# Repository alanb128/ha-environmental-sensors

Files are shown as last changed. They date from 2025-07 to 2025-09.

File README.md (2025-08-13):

# Environmental sensors
Two different sensor projects that can be used standalone or with Home Assistant

Watch the video: https://youtu.be/DV3xqJKjhDA

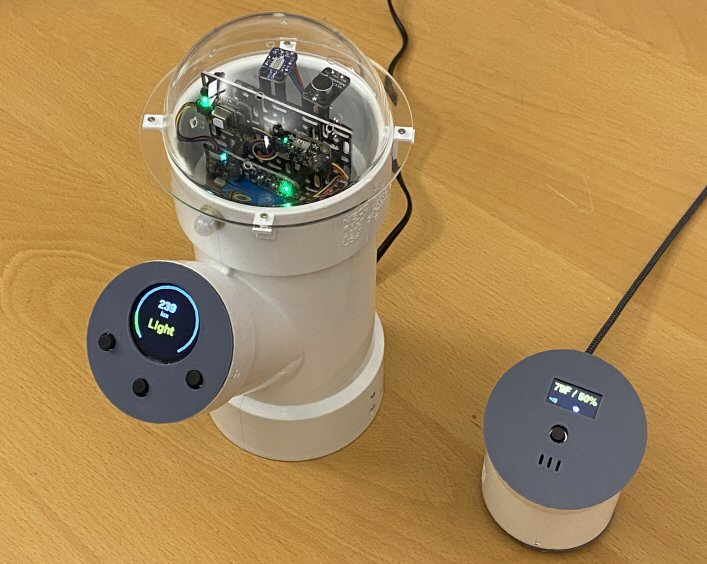
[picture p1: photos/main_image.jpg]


Disclaimer: These devices are not for any safety, medical, or critical usage. It's for hobby education and experimentation only!

## Mini-sensor

This one is designed to be inexpensive and easy to build. The parts should cost around $25. It measures temperature and humidity, and can publish the sensor readings to Home Assistant.

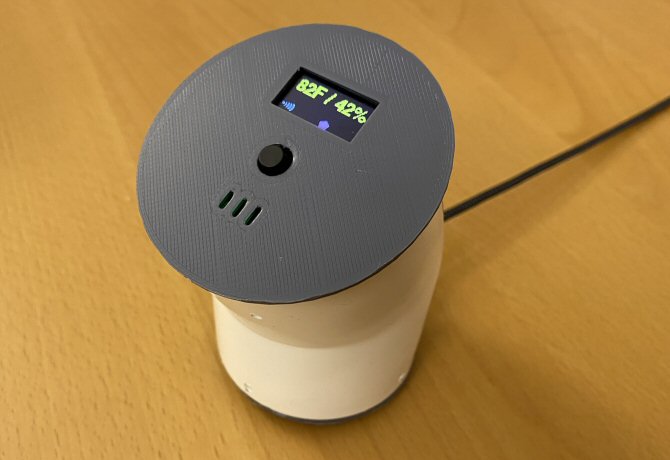
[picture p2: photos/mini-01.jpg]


### Hardware List

- [Raspberry Pi Pico 2W](https://www.raspberrypi.com/products/raspberry-pi-pico-2/) microcontroller
- The case is based on a "2 Inch 22.5 Degree PVC Elbow Pipe Fitting" [like this one](https://www.amazon.com/dp/B0DZS46D2V)
- Display (optional) [Adafruit 0.96" 160x80 Color TFT Display](https://www.adafruit.com/product/3533) - ST7735
- 12mm x 12mm momentary tactile button (optional)
- Some wire or ribbon cable, 28AWG or similar
- [3cm x 7cm proto board](https://www.adafruit.com/product/4784) (only one board needed per sensor)
- [SHT40 Temperature and Humidity Sensor](https://www.adafruit.com/product/4885) (or SHT41, SHT45)
- M2 x 12 self tapping screws (optional) - 4 pieces to secure top and bottom to case

If not using the display, you can use an LED instead:
- bi-color LED
- two 470 ohm resistors

### Assembly

3D print the top, bottom, and insulator. Then use the photos below to help assemble the unit. The file `schematic-mini.pdf` shows how to wire everything together.

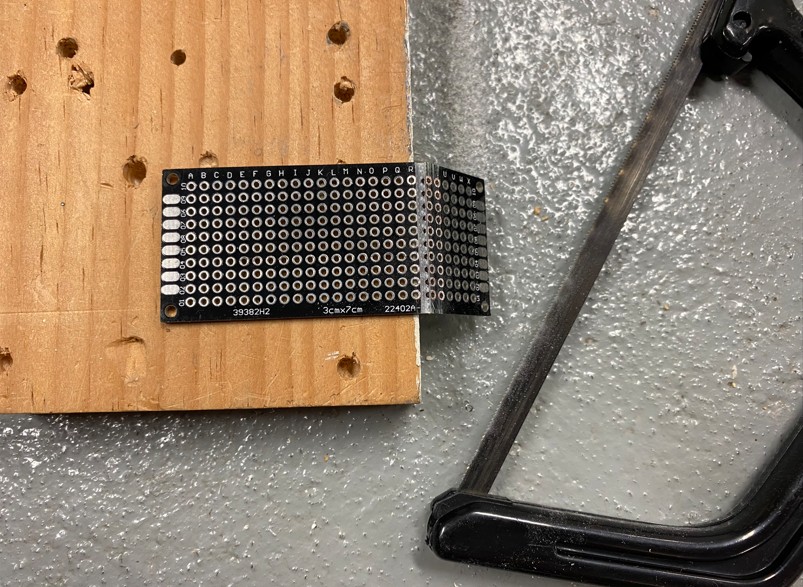
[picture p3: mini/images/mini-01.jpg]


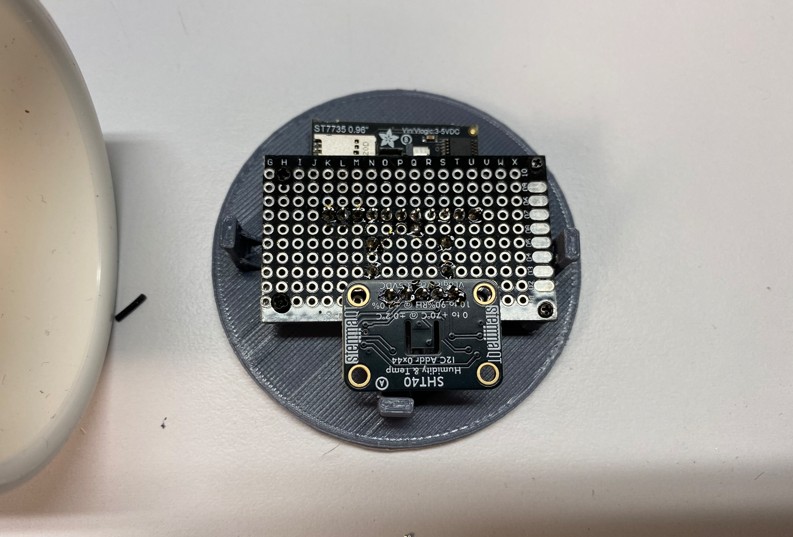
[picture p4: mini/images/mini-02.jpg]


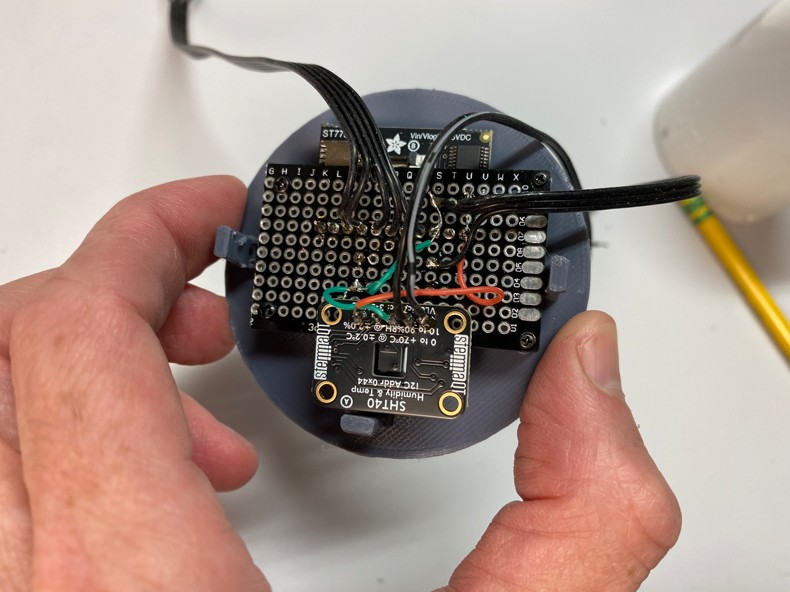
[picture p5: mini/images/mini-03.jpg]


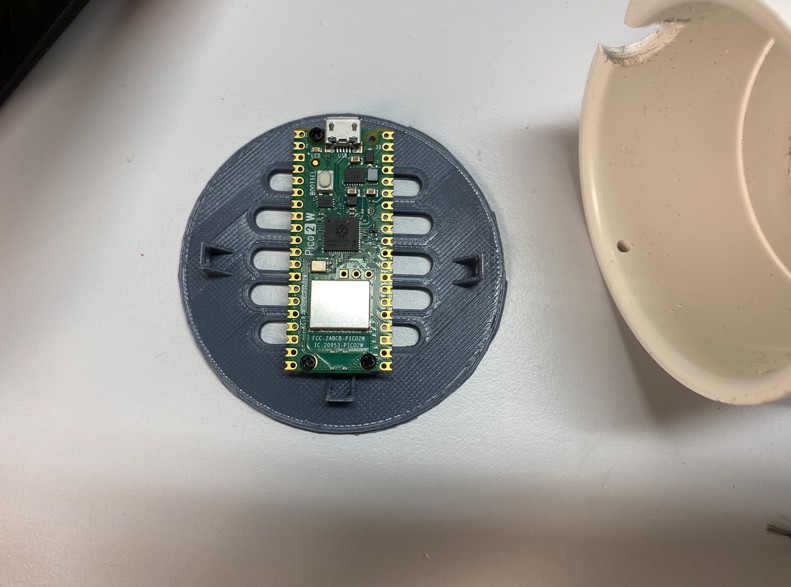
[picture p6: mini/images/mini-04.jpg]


### Software

[Download and install](https://circuitpython.org/board/raspberry_pi_pico2_w/) Circuitpython for the Pico 2W. This code was developed and tested on version 9.2.7, but should work on newer versions. 

Copy all of the files in the mini folder to the root of your Pico. (This includes all of the code and icons needed to run the project) You'll be replacing the default code.py file if it already exists.  

You will need to find and download the font file `Helvetica-Bold-16.bdf` to the root of the Pico as well. (I can't host it here due to its proprietary nature.)

Edit the `settings.toml` file with your WiFi SSID and password.

Add the following libraries to the Lib folder on the device: (You can find them in [the bundles](https://circuitpython.org/libraries) for version 9.x)

- adafruit_bitmap_font
- adafruit_minimqtt
- adafruit_display_text
- adafuit_ticks
- adafruit_st7735r
- adafruit_sht4x
- adafruit_connection_manager

### Operation

Provide 5v 1A or greater to the Pico's micro usb port to power the device and start the code automatically. Update the settings file to publish via MQTT.

## Maxi

This one has up to ten sensors and is a more advanced project. The full code and some build suggestions are in this repo, but you'll need to improvise a little bit for best results.

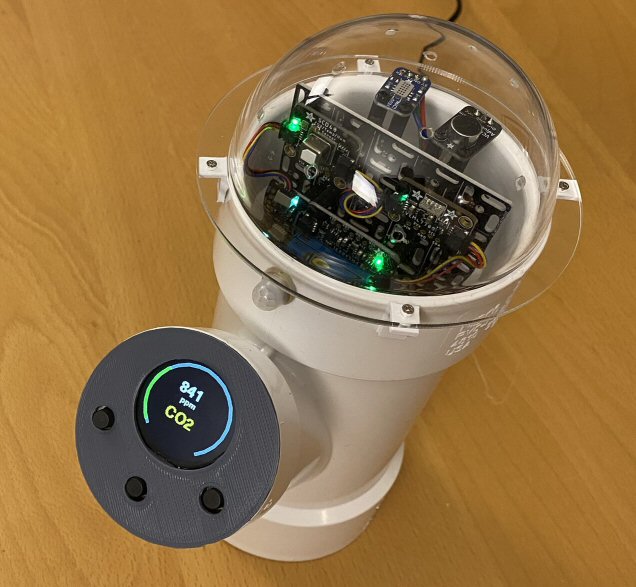
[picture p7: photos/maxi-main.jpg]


### Hardware List

- [Raspberry Pi Pico 2W](https://www.raspberrypi.com/products/raspberry-pi-pico-2/) microcontroller
- The case is based on a "Reducing" pipe fitting, [like this one](https://www.homedepot.com/p/Charlotte-Pipe-3-in-x-3-in-x-2-in-DWV-PVC-Wye-Reducing-PVC006011400HD/203396277) 
- 12mm x 12mm momentary tactile buttons (three)
- Some wire or ribbon cable, 28AWG or similar
- [Swirly Aluminum Grids](https://www.adafruit.com/product/5774) (mix and match, cut to size if needed)
- [Basic PIR Sensor like the BL412](https://www.adafruit.com/product/4667) 
- [Adafruit EYESPI breakout board](https://www.adafruit.com/product/5613) For connecting display ribbon cable to the Pico
- [MAX 4466 electret microphone](https://www.adafruit.com/product/1063)
- [Tiny Code Reader from Useful Sensors](https://www.adafruit.com/product/5744)
- [Adafruit MiCS5524 gas sensor](https://www.adafruit.com/product/3199)
- [DPS 310 Pressure sensor](https://www.adafruit.com/product/4494)
- [Accelerometer](https://www.adafruit.com/product/2809)
- [VEML7700 Lux Sensor](https://www.adafruit.com/product/4162)
- [SCD 40](https://www.adafruit.com/product/5187) CO2 sensor
- [Adafruit PMSA003I Air Quality Breakout](https://www.adafruit.com/product/4632)
- [4 channel I2C-safe logic level converter](https://www.adafruit.com/product/757)
- [Adafruit 1.28" 240x240 Round TFT LCD](https://www.adafruit.com/product/6178)
- Qwiic/STEMMAQT connectors/cables to connect the sensors together
- M2.5 spacers, standoffs and hardware for mounting sensors
- [3cm x 7cm proto board](https://www.adafruit.com/product/4784) - cut as needed
- 5V, 4A power supply
- The top dome (optional) is a CCTV clear dome [like this one](https://www.amazon.com/dp/B07L6GLTNP)

Optional:
- blue LED and resistor
- acrylic security camera dome

### Assembly

3D print the control panel, bottom bracket, and clips. Then use the photos below to help assemble the unit. The file `schematic-maxi.pdf` shows how to wire everything together.

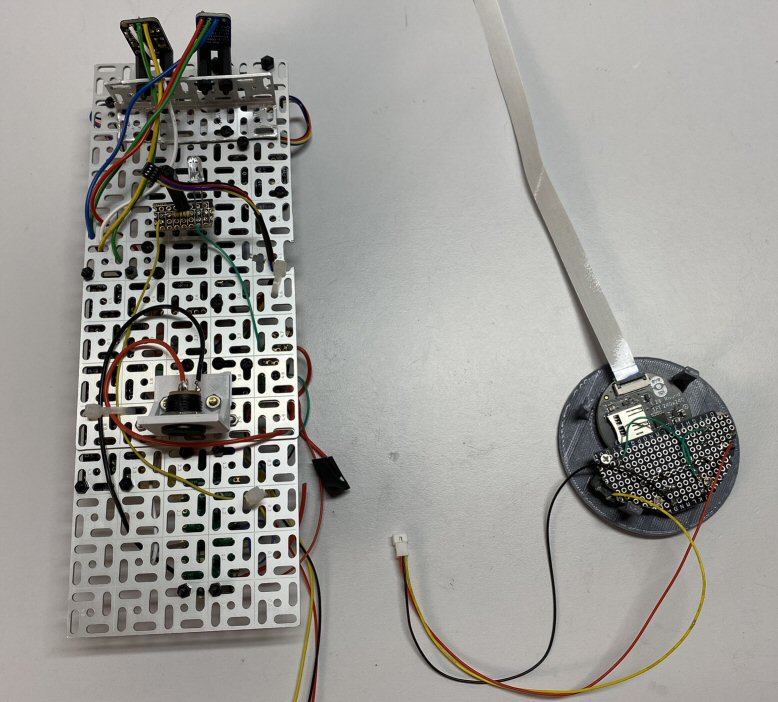
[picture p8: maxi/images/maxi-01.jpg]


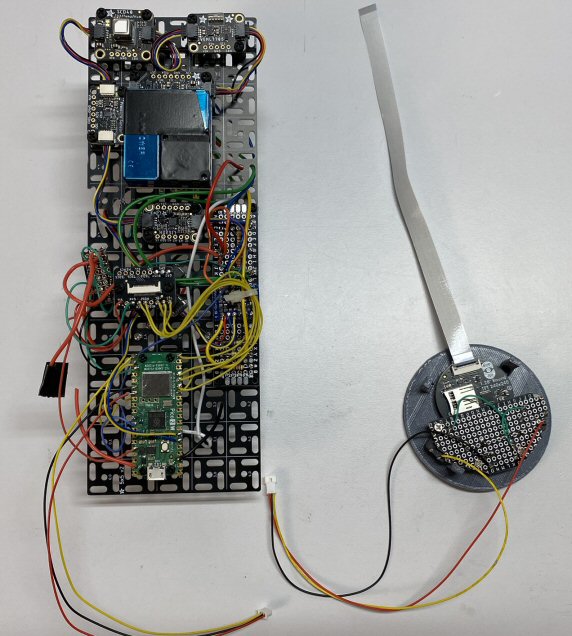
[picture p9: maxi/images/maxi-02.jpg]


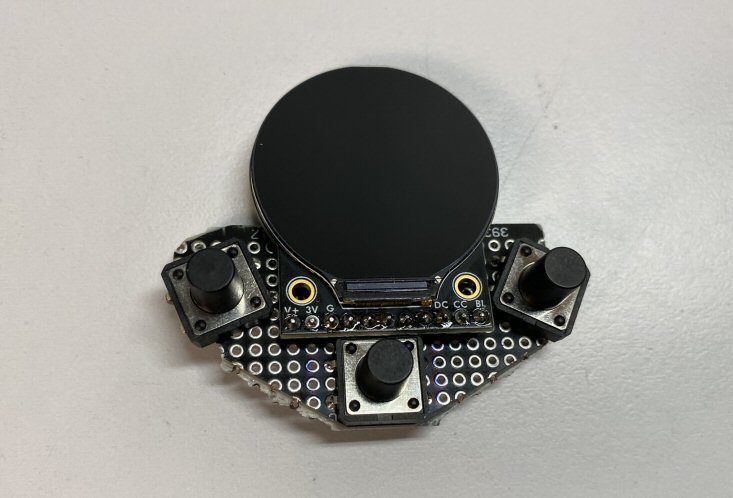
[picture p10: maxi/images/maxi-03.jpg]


### Software

[Download and install](https://circuitpython.org/board/raspberry_pi_pico2_w/) Circuitpython for the Pico 2W. This code was developed and tested on version 9.2.7, but should work on newer versions. 

Copy all of the files in the maxi folder to the root of your Pico. (This includes all of the code and icons needed to run the project) You'll be replacing the default code.py file if it already exists.  

You will need to find and download the font file `Helvetica-Bold-16.bdf` to the root of the Pico as well. (I can't host it here due to its proprietary nature.)

Edit the `settings.toml` file with your WiFi SSID and password.

Add the following libraries to the Lib folder on the device: (You can find them in [the bundles](https://circuitpython.org/libraries) for version 9.x)

- adafruit_bitmap_font
- adafruit_bus_device
- adafruit_display_shapes
- adafruit_minimqtt
- adafruit_display_text
- adafruit_imageload
- adafruit_dps310
- adafruit_pm25
- adafruit_register
- adafuit_ticks
- adafruit_gc9a01a
- adafruit_lis3dh
- adafruit_scd4x
- adafruit_veml7700
- adafruit_connection_manager

### Operation

Provide 5v 4A or greater to the Pico's VSYS pin to power the device and start the code automatically. Update the settings file to publish via MQTT. Note that most of the I2C sensors need to be powered by the 5V supply and then connected to the Pico through the logic level shifter. (See the schematic) When trying to power everything on the I2C bus with 3V, the sensors would brown out every few seconds. Make sure the sensors you choose are all 5V tolerant. (The ones in the parts list are.)

## Connecting to Home Assistant

You will need an MQTT broker running on your network. [Mosquitto](https://mosquitto.org/) is a good choice!

Then, [add the sensors](https://www.home-assistant.io/integrations/sensor.mqtt/) and binary sensors to your configuration.yaml file in Home Assistant. 

For an example of the House Map dashboard configuration, see the `house-map.txt` file in this repo. Note that it uses an image uploaded to the Home Assistant media folder.

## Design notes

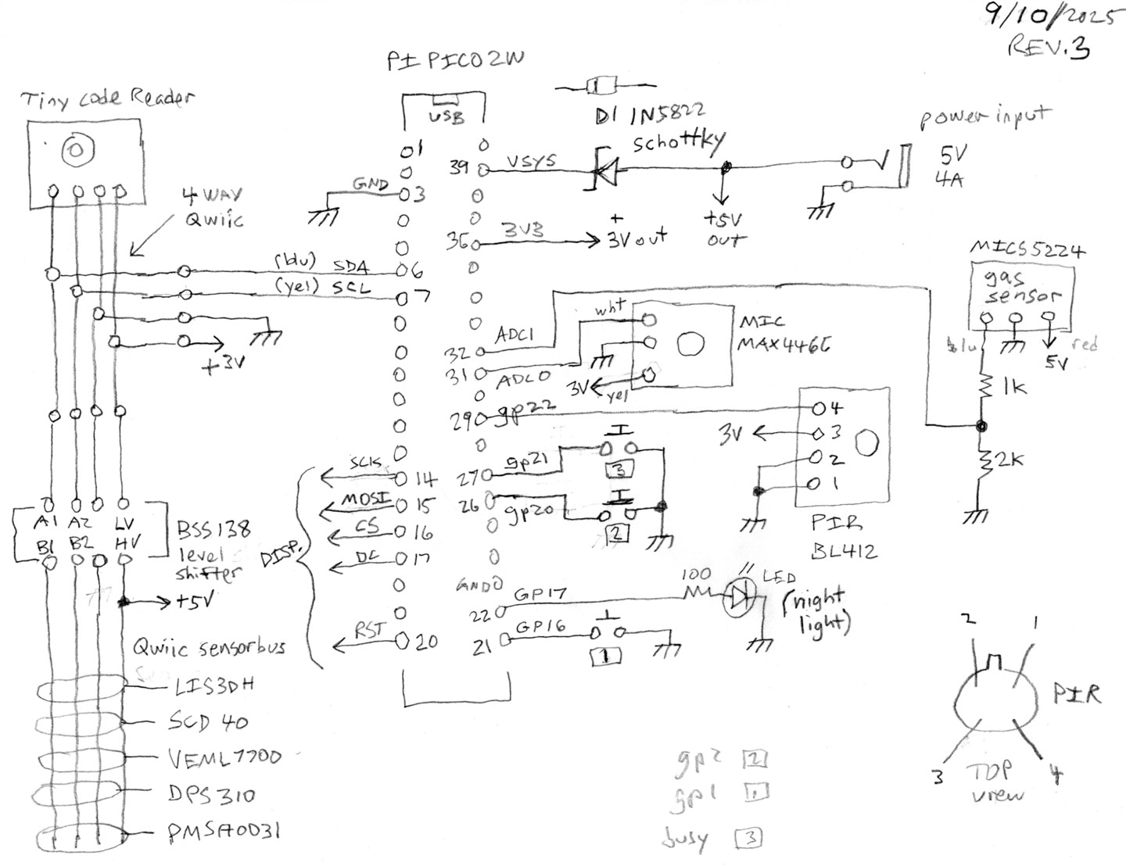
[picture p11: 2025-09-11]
schematic-maxi.jpg

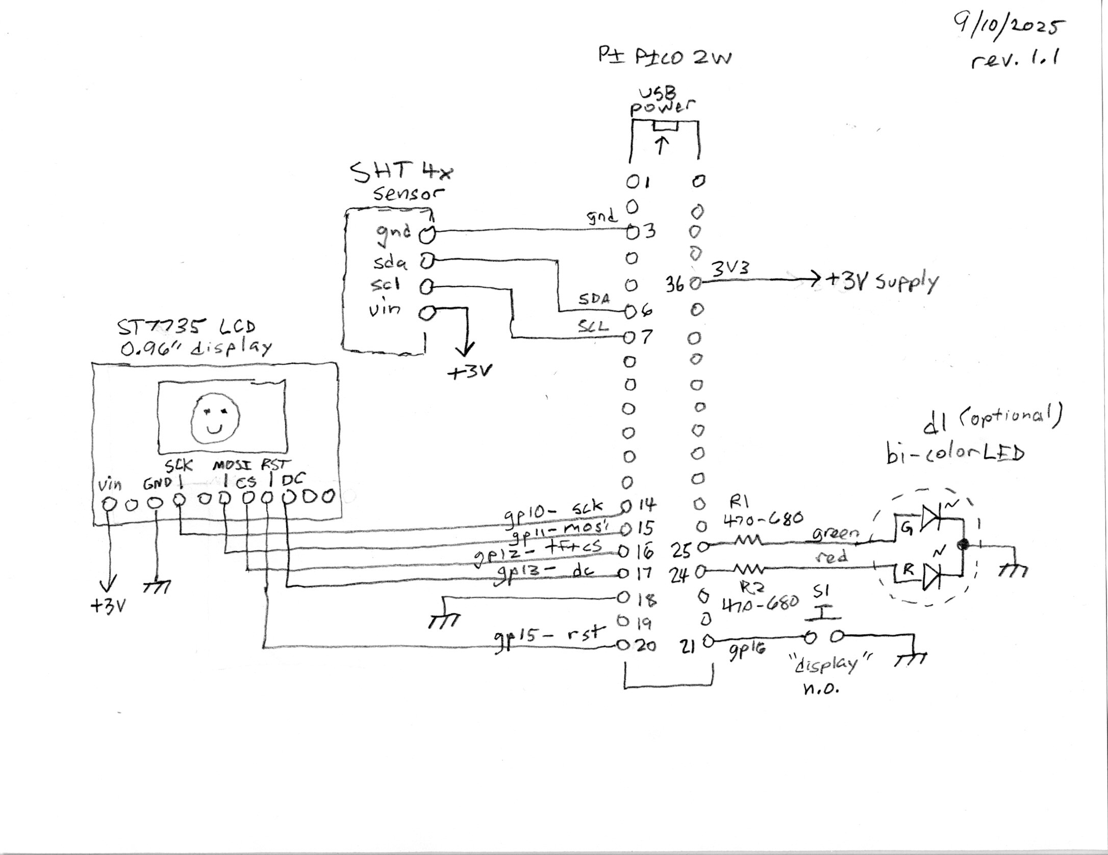
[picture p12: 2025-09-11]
schematic-mini.jpg

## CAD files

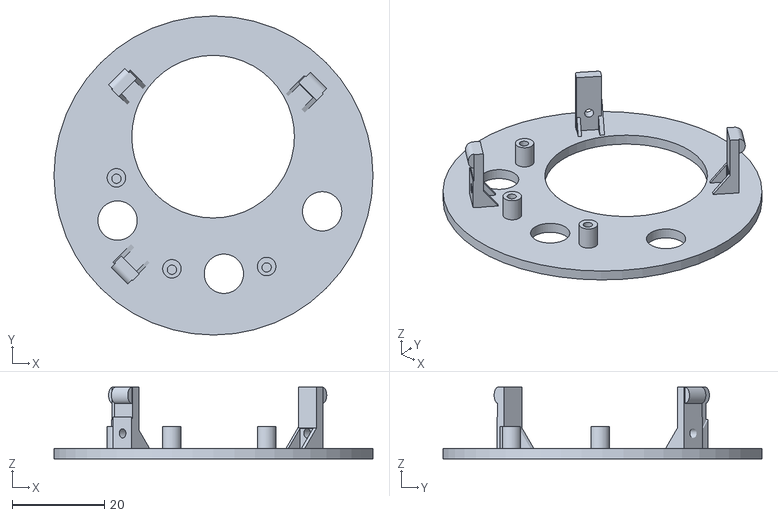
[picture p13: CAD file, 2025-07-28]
maxi/stl/control-panel.stl
69.0 x 69.0 x 15.5

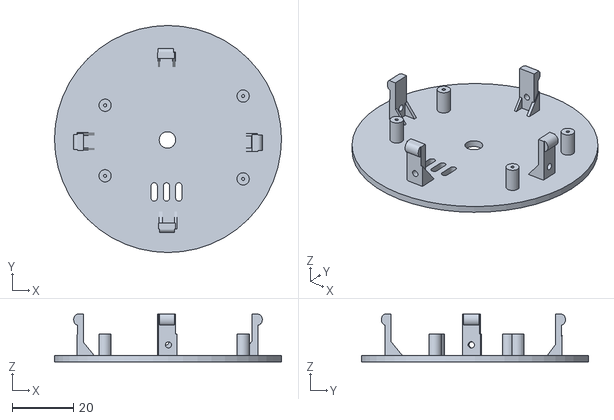
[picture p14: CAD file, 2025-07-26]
mini/stl/top-no-lcd.stl
74.0 x 74.0 x 15.5

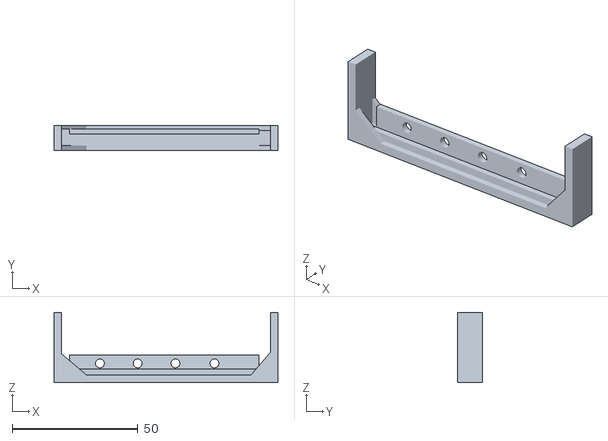
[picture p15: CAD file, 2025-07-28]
maxi/stl/bottom-bracket.stl
89.0 x 10.0 x 28.0

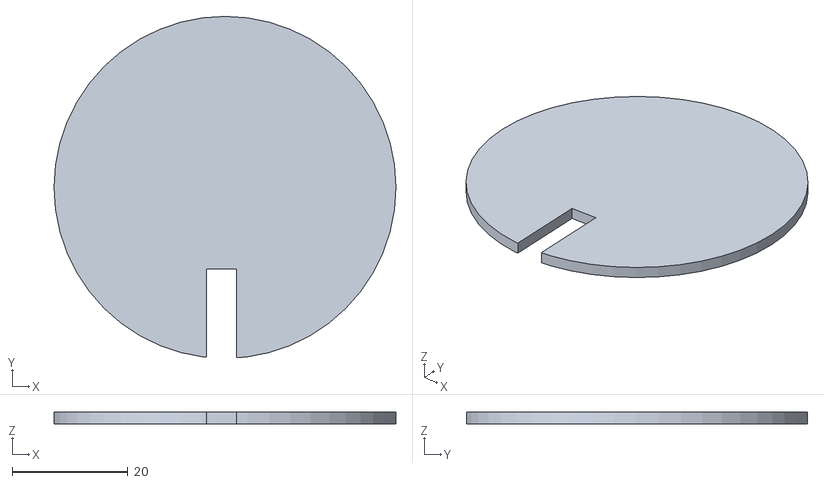
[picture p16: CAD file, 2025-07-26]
mini/stl/insulator.stl
59.0 x 58.9 x 2.00

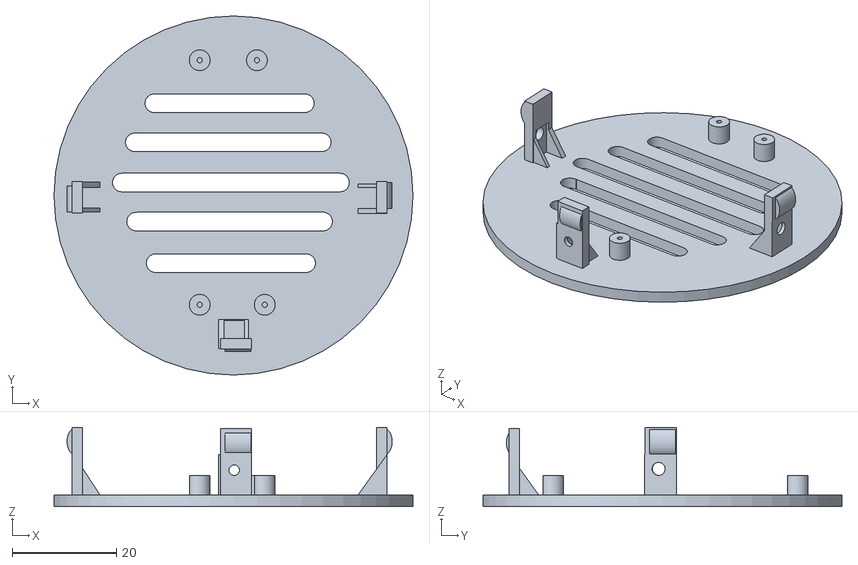
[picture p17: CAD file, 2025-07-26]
mini/stl/bottom.stl
69.0 x 69.0 x 15.2

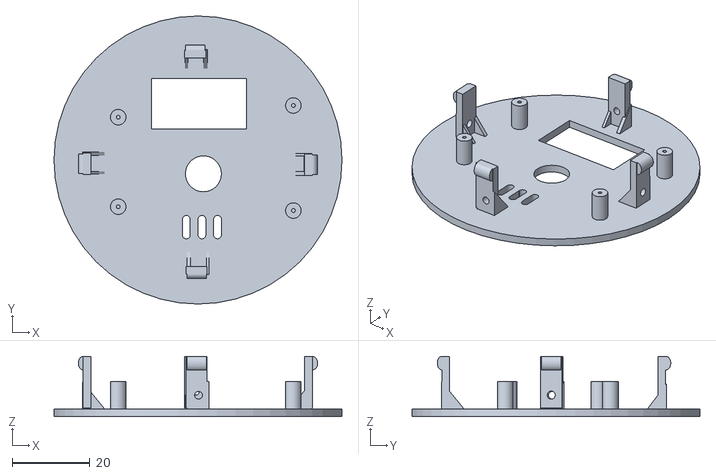
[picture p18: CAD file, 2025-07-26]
mini/stl/top.stl
74.0 x 74.0 x 15.5

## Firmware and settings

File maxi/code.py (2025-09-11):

# SPDX-FileCopyrightText: 2021 ladyada for Adafruit Industries
# SPDX-License-Identifier: MIT

import time
import os
import board
import busio
import digitalio
from analogio import AnalogIn
import microcontroller
import struct

import adafruit_lis3dh
from digitalio import DigitalInOut, Direction, Pull

from adafruit_pm25.i2c import PM25_I2C
from adafruit_dps310.basic import DPS310
import adafruit_veml7700
import adafruit_scd4x

import displayio
import terminalio
from adafruit_display_text.bitmap_label import Label
import adafruit_imageload
from fourwire import FourWire
from vectorio import Circle
from adafruit_gc9a01a import GC9A01A
from adafruit_display_shapes.arc import Arc
from adafruit_bitmap_font import bitmap_font
from adafruit_display_text import label

import ipaddress
import wifi
import socketpool
import ssl
import adafruit_minimqtt.adafruit_minimqtt as MQTT

print("Hello.")

def take_reading(sensor):
    
    global pm10
    global pm25
    global hum
    pm1 = 0
    co2 = 0
    reading = 0
      
    if sensor == "PM1":
    
        try:
            aqdata = pm_25.read()
            # print(aqdata)
            print()
            print("Concentration Units (standard)")
            print("---------------------------------------")
            print(
                "PM 1.0: %d\tPM2.5: %d\tPM10: %d"
                % (aqdata["pm10 standard"], aqdata["pm25 standard"], aqdata["pm100 standard"])
            )
            pm25 = aqdata["pm25 standard"]
            pm10 = aqdata["pm100 standard"]
            pm1 = aqdata["pm10 standard"]
        except Exception as e:
            print("Unable to read from PM sensor: {}; retrying...".format(e))
            time.sleep(1.2)
            try:
                aqdata = pm_25.read()
                # print(aqdata)
                print()
                print("Concentration Units (standard)")
                print("---------------------------------------")
                print(
                    "PM 1.0: %d\tPM2.5: %d\tPM10: %d"
                    % (aqdata["pm10 standard"], aqdata["pm25 standard"], aqdata["pm100 standard"])
                )
                pm25 = aqdata["pm25 standard"]
                pm10 = aqdata["pm100 standard"]
                pm1 = aqdata["pm10 standard"]
            except Exception as e:
                print("Unable to read from PM sensor: {}.".format(e))
                pm25 = 0
                pm10 = 0
                pm1 = 0
        reading = pm1
    
    elif sensor == "PM2.5":
        reading = pm25

    elif sensor == "PM10":
        reading = pm10
    
    elif sensor == "Temp":
        #print("Temperature = %.2f *C" % dps310.temperature)
        reading = round((dps310.temperature * 1.8) + 32)
    
    
    elif sensor == "Pres":
        #print("Pressure = %.2f hPa" % dps310.pressure)
        reading = round(dps310.pressure)
    
    elif sensor == "Light":
        #print("Ambient light:", veml7700.light)
        reading = veml7700.light
    
    elif sensor == "CO2":
        
        if scd4x.data_ready:
            #print("CO2: %d ppm" % scd4x.CO2)
            #print("Temperature: %0.1f *C" % scd4x.temperature)
            #print("Humidity: %0.1f %%" % scd4x.relative_humidity)
            #print()
            hum = round(scd4x.relative_humidity)
            co2 = scd4x.CO2
        else:
            print("Waiting for CO2 ready...")
            time.sleep(1.33)
            if scd4x.data_ready:
                hum = scd4x.relative_humidity
                co2 = scd4x.CO2
        reading = co2
    
    elif sensor == "Hum":
        
        reading = hum
    
    elif sensor == "Gas":
        
        reading = int(analog_range(gas_pin.value))
    
    elif sensor == "Sound":
        
        reading = int(analog_range(mic_pin.value))
    
    else:
        print("Unknown sensor request {}.".format(sensor))
        reading = 0
    
    publish_it(sensor, reading)
    return reading

def angle_range(OldValue, OldMin, OldMax):
    #print(OldValue, OldMin, OldMax)
    # https://stackoverflow.com/a/929107
    NewMax = 280
    NewMin = 5
    OldRange = (OldMax - OldMin)  
    NewRange = (NewMax - NewMin)
    #print(OldValue, OldMin, NewRange, OldRange, NewMin)
    NewValue = (((OldValue - OldMin) * NewRange) / OldRange) + NewMin
    
    return NewValue

def direction_range(OldValue):
    
    OldMax = 280
    OldMin = 5
    NewMax = 130
    NewMin = 0
    OldRange = (OldMax - OldMin)  
    NewRange = (NewMax - NewMin)  
    NewValue = (((OldValue - OldMin) * NewRange) / OldRange) + NewMin
    
    return 220 - NewValue
    
def arc_measure(reading, minimum, middle, high, maximum):
    
    angle = angle_range(reading, minimum, maximum)
    arc.angle = angle
    arc.direction = direction_range(angle)
    if reading > middle:
        arc.fill=0xFFFF00
    elif reading > high:
        arc.fill=0xFF0000
    else:
        arc.fill=0x00FF00

def analog_range(OldValue):
    
    # https://stackoverflow.com/a/929107
    OldMin = 0
    OldMax = 65535
    NewMax = 100
    NewMin = 0
    OldRange = (OldMax - OldMin)  
    NewRange = (NewMax - NewMin)
    #print(OldValue, OldMin, NewRange, OldRange, NewMin)
    NewValue = (((OldValue - OldMin) * NewRange) / OldRange) + NewMin
    
    return NewValue

def show_info():
    
    global screen_mode
    global mode_count
    
    mode_count = 0
    
    if screen_mode == 0 or screen_mode == 2:
        screen_mode = 1
        group_scan.hidden = True
        group_readings.hidden = True
        group_info.hidden = False
        
        
    else:
        screen_mode = 0
        group_info.hidden = True
        group_scan.hidden = True
        group_readings.hidden = False
        
    if wifi_connect:
        tile_grid3.hidden = False
    else:
        tile_grid3.hidden = True
        
    if mqtt_connect:
        tile_grid4.hidden = False
    else:
        tile_grid4.hidden = True
        
        
def show_scan():
    
    global screen_mode
    global mode_count
    
    mode_count = 0
    
    if screen_mode == 0 or screen_mode == 1:
        screen_mode = 2
        group_readings.hidden = True
        group_info.hidden = True
        text_area_s1.text = "Scan QR..."
        text_area_s2.color = 0xFFFF00
        text_area_s2.text = "Waiting..."
        group_scan.hidden = False
        
        
    else:
        screen_mode = 0
        group_info.hidden = True
        group_scan.hidden = True
        group_readings.hidden = False

def show_reading():
    
    group_info.hidden = True
    group_scan.hidden = True
    group_readings.hidden = False
        
def connected(client, userdata, flags, rc):
    # This function will be called when the client is connected
    # successfully to the broker.
    global mqtt_connect
    print(f"Connected to the MQTT broker!")
    #tile_grid3.hidden = False
    mqtt_connect = True
    print("Subscribing to led1 topic.")
    client.subscribe("/beast/led1")

def disconnected(client, userdata, rc):
    # This method is called when the client is disconnected
    global mqtt_connect
    print("Disconnected from the MQTT broker!")
    #tile_grid3.hidden = True
    mqtt_connect = False

def publish_it(subtopic, read_value):
    
    global mqtt_connect
    
    if not wifi_connect:
        #print("Not connected to wifi, skipping publish.")
        return
    else:
        if not mqtt_connect:
            #print("Not connected to MQTT broker; skipping publish")
            return
    
    #tile_grid4.hidden = False
    #print("here: {}, {}".format(deg_f, temperature))
    try:
        mqtt_client.publish(TOPIC + "/" + subtopic, read_value)
    except:
        print("Error publishing MQTT {}".format(subtopic))
        mqtt_connect = False

def message(client, topic, message):
    # This method is called when a topic the client is subscribed to
    # has a new message.
    print("New MQTT message: {}; topic: {}".format(message, topic))

    if topic == "/beast/led1":
        if message == "1":
            pir_led.value = True
        else:
            pir_led.value = False
            
def connect_wifi(force):
    
    global wifi_connect
    
    
    print("Attempting connection to WiFi...")

    #  connect to your SSID if not connected unless forced
    if (not wifi_connect) or force:
        try:
            wifi.radio.connect(ssid, pw)
        except:
            print("Could not connect to WiFi!")
            tile_grid.hidden = True
            wifi_connect = False
        else:
            wifi_connect = True
            tile_grid.hidden = False
            print("Connected to WiFi")
            print("My IP address is ", wifi.radio.ipv4_address)
              
            
def connect_mqtt(retry):
    
    global mqtt_connect
    
    # Connect the client to the MQTT broker.
    print("Connecting to the MQTT broker...")
    if wifi_connect:
        try:
            mqtt_client.connect()
        except:
            print("Error trying to connect to MQTT broker")
            mqtt_connect = False
    else:
        print("Not connected to WiFi, skipping broker connection attempt.")
    

def code_read():
    
    read_data = bytearray(TINY_CODE_READER_I2C_BYTE_COUNT)
    while not i2c.try_lock():
        # Keep trying until the lock is acquired
        print("Trying to lock I2C for reader...:")
        time.sleep(0.5)
        
    try:
        try:
            i2c.readfrom_into(TINY_CODE_READER_I2C_ADDRESS, read_data)
        except:
            print("Error reading QR - is device attached?")
        else:
            print("QR code read.")
            #print(i2c.scan())
    finally:
        i2c.unlock()
        

    message_length,  = struct.unpack_from(TINY_CODE_READER_LENGTH_FORMAT, read_data, TINY_CODE_READER_LENGTH_OFFSET)
    message_bytes = struct.unpack_from(TINY_CODE_READER_MESSAGE_FORMAT, read_data, TINY_CODE_READER_MESSAGE_OFFSET)
    print(message_length)

    if message_length > 0:
        try:
            message_string = bytearray(message_bytes[0:message_length]).decode("utf-8")
            print("Code reader msg: {}".format(message_string))
            return message_string
        except:
            print("Couldn't decode reader as UTF 8")
            return "Empty"
    else:
        print("QR message empty.")
        return "Empty"

def read_scan_data(qr_data):
    
    global ssid
    global pw
    
    # Sample WiFi data: WIFI:T:WPA;S:MyNet;P:QW6HN8IKL9;H:;;

    if qr_data.startswith("WIFI:"):
        # Remove the "WIFI:" prefix
        data_string = qr_data[5:]
        
        # Split into individual components
        components = data_string.split(';')
        
        for comp in components:
            if comp.startswith("S:"):
                ssid = comp[2:]
            elif comp.startswith("T:"):
                pass
            elif comp.startswith("P:"):
                pw = comp[2:]
        text_area_s2.color = 0x00FF00
        text_area_s2.text = "Accepted!"
        print("WiFi credentials received!")
        
        connect_wifi(True)
        
    else:
        text_area_s2.color = 0xFF0000
        text_area_s2.text = "Rejected!"
        print("QR code not for WiFi!")
    
    time.sleep(1.25)
    
def do_pir():
    
    global pir_led
    
    if pir_active:
        # turn on LED
        pir_led.value = True
        # publish
        publish_it("motion", 1)
    else:
        # turn off led
        pir_led.value = False
        # publish
        publish_it("motion", 0)
        
        
sensors = {
    "Light": {
        "unit": "lux",
        "minimum": 0,
        "middle": 1000,
        "high": 1500,
        "maxi": 2000
        },
    "CO2": {
        "unit": "ppm",
        "minimum": 0,
        "middle": 1000,
        "high": 2000,
        "maxi": 3000
        },
    "Temp": {
        "unit": "F",
        "minimum": 0,
        "middle": 72,
        "high": 85,
        "maxi": 120
        },
    "Hum": {
        "unit": "%",
        "minimum": 0,
        "middle": 50,
        "high": 60,
        "maxi": 100
        },
    "Pres": {
        "unit": "hPa",
        "minimum": 970,
        "middle": 1020,
        "high": 1030,
        "maxi": 1050
        },
    "PM1": {
        "unit": "ppm",
        "minimum": 0,
        "middle": 25,
        "high": 50,
        "maxi": 100
        },
    "PM2.5": {
        "unit": "ppm",
        "minimum": 0,
        "middle": 35,
        "high": 55,
        "maxi": 120
        },
    "PM10": {
        "unit": "ppm",
        "minimum": 0,
        "middle": 53,
        "high": 150,
        "maxi": 220
        },
    "Sound": {
        "unit": "lvl",
        "minimum": 0,
        "middle": 75,
        "high": 90,
        "maxi": 100
        },
    "Gas": {
        "unit": "lvl",
        "minimum": 0,
        "middle": 50,
        "high": 75,
        "maxi": 100
        }
    }
pages = ["Light","CO2","Temp","Hum","Pres","PM1","PM2.5","PM10","Sound","Gas"]
page = 0
screen_mode = 0
mode_count = 0
mqtt_reconnect_count = 0
wifi_reconnect_count = 0
mqtt_connect = False
wifi_connect = False
ssid = ""
pw = ""
pir_active = False
pir_active_count = 0

# MQTT settings:
TIMEOUT = None
HOST = os.getenv('MQTT_HOST')
PORT = os.getenv('MQTT_PORT')
TOPIC = os.getenv('TOPIC_PATH')

# for caching
pm25 = 0
pm10 = 0
temp = 0
hum = 0


# Set up display
displayio.release_displays()

spi = busio.SPI(clock=board.GP10, MOSI=board.GP11) #, MISO=board.GP16)
tft_cs = board.GP12
tft_dc = board.GP13
tft_reset=board.GP15



display_bus = FourWire(spi, command=tft_dc, chip_select=tft_cs, reset=tft_reset)
display = GC9A01A(display_bus, width=240, height=240)

# Set up screens
group_main = displayio.Group()
group_readings = displayio.Group()
group_info = displayio.Group()
group_scan = displayio.Group()
group_info.hidden = True
group_scan.hidden = True

display.root_group = group_main

group_metric = displayio.Group(scale=2, x=65, y=145)
text = "Startup"
#font = bitmap_font.load_font("/Helvetica-Bold-16.bdf")
font = bitmap_font.load_font("/helvB14.bdf")
text_metric = label.Label(font, text=text, color=0xFFFF00)
group_metric.append(text_metric) # Subgroup for text scaling
group_readings.append(group_metric)

group_value = displayio.Group(scale=2, x=70, y=75)
text = "    0"
font = bitmap_font.load_font("/helvB14.bdf")
text_value = label.Label(font, text=text, color=0xFFFFFF)
group_value.append(text_value) # Subgroup for text scaling
group_readings.append(group_value)

group_units = displayio.Group(scale=1, x=95, y=105)
text = "hello"
font = bitmap_font.load_font("/helvB14.bdf")
text_units = label.Label(font, text=text, color=0xFFFFFF)
group_units.append(text_units) # Subgroup for text scaling
group_readings.append(group_units)

arc = Arc(x=120, y=120, radius=110, angle=5, direction=220, segments=20, arc_width=8, fill=0x00FF00)
bg_arc = Arc(x=120, y=120, radius=110, angle=280, direction=90, segments=20, arc_width=8, fill=0x808080)
group_readings.append(bg_arc)
group_readings.append(arc)


# Add this group to the root group
group_main.append(group_readings)

# Set up the info page
text_info1 = displayio.Group(x=24, y=100)
text_info2 = displayio.Group(x=24, y=120)
text_info3 = displayio.Group(x=24, y=140)
text_info4 = displayio.Group(x=24, y=160)
text_info5 = displayio.Group(x=40, y=180)
text = "ip: " + "192.168.1.55" #str(wifi.radio.ipv4_address)
text_area_f3 = label.Label(font, text=text, color=0xFFFFFF)
text = "sw v. " + os.getenv('SW_VERSION')
text_area_f1 = label.Label(font, text=text, color=0xFFFFFF)
text = "cpu temp: " + str(int(microcontroller.cpu.temperature))
text_area_f2 = label.Label(font, text=text, color=0xFFFFFF)
text = "mqtt: " + os.getenv('MQTT_HOST')
text_area_f4 = label.Label(font, text=text, color=0xFFFFFF)
text = "port: " + str(os.getenv('MQTT_PORT'))
text_area_f5 = label.Label(font, text=text, color=0xFFFFFF)
text_info1.append(text_area_f1)
text_info2.append(text_area_f2)
text_info3.append(text_area_f3)
text_info4.append(text_area_f4)
text_info5.append(text_area_f5)
group_info.append(text_info1)
group_info.append(text_info2)
group_info.append(text_info3)
group_info.append(text_info4)
group_info.append(text_info5)
# Add the settings page image
bitmap1 = displayio.OnDiskBitmap("/info.bmp")
# Create a TileGrid to hold the bitmap
tile_grid = displayio.TileGrid(bitmap1, pixel_shader=bitmap1.pixel_shader, x=100,y=35)
# Add the TileGrids to the Group
group_info.append(tile_grid)

# add the wifi and mqtt icons
bitmap3 = displayio.OnDiskBitmap("/wifi.bmp")
# Create a TileGrid to hold the bitmap
tile_grid3 = displayio.TileGrid(bitmap3, pixel_shader=bitmap1.pixel_shader, x=75,y=200)
# Add the TileGrids to the Group
group_info.append(tile_grid3)

bitmap4 = displayio.OnDiskBitmap("/mqtt.bmp")
# Create a TileGrid to hold the bitmap
tile_grid4 = displayio.TileGrid(bitmap4, pixel_shader=bitmap1.pixel_shader, x=110,y=200)
# Add the TileGrids to the Group
group_info.append(tile_grid4)

# Add this group to the root group
group_main.append(group_info)

# WiFi and MQTT start out hidden
tile_grid3.hidden = True
tile_grid4.hidden = True

# Set up the scan page
text_scan1 = displayio.Group(scale=2, x=17, y=120)
text_scan2 = displayio.Group(x=75, y=165)

text = "Scan QR now"
text_area_s1 = label.Label(font, text=text, color=0xFFFFFF)

text_scan1.append(text_area_s1)

group_scan.append(text_scan1)

text = "waiting..."
text_area_s2 = label.Label(font, text=text, color=0xFFFF00)

text_scan2.append(text_area_s2)

group_scan.append(text_scan2)

# Add the scan page image
bitmap2 = displayio.OnDiskBitmap("/qr.bmp")
# Create a TileGrid to hold the bitmap
tile_grid2 = displayio.TileGrid(bitmap2, pixel_shader=bitmap1.pixel_shader, x=100,y=40)
# Add the TileGrids to the Group
group_scan.append(tile_grid2)

# Add this group to the root group
group_main.append(group_scan)
# -------------------------------------------------------------

# GPIO /ADC

btn1 = digitalio.DigitalInOut(board.GP21)
btn1.direction = digitalio.Direction.INPUT
btn1.pull = digitalio.Pull.UP

btn2 = digitalio.DigitalInOut(board.GP20)
btn2.direction = digitalio.Direction.INPUT
btn2.pull = digitalio.Pull.UP

btn3 = digitalio.DigitalInOut(board.GP16)
btn3.direction = digitalio.Direction.INPUT
btn3.pull = digitalio.Pull.UP

pir = digitalio.DigitalInOut(board.GP22)
pir.direction = digitalio.Direction.INPUT
pir.pull = digitalio.Pull.DOWN

pir_led = digitalio.DigitalInOut(board.GP17)
pir_led.direction = digitalio.Direction.OUTPUT

mic_pin = AnalogIn(board.A0)
gas_pin = AnalogIn(board.A1)


i2c = busio.I2C(scl=board.GP5, sda=board.GP4)

# LIS3DH
lis3dh = adafruit_lis3dh.LIS3DH_I2C(i2c)
# Set range of accelerometer (can be RANGE_2_G, RANGE_4_G, RANGE_8_G or RANGE_16_G).
lis3dh.range = adafruit_lis3dh.RANGE_2_G

#PM25
reset_pin = None
# Connect to a PM2.5 sensor over I2C
pm_25 = PM25_I2C(i2c, reset_pin)
print("Found PM2.5 sensor, reading data...")

#DPS310
dps310 = DPS310(i2c)

#VEML7700
veml7700 = adafruit_veml7700.VEML7700(i2c)

text_value.text = "  25"
arc_measure(25, 0, 101, 101, 100)

#SCD4X
scd4x = adafruit_scd4x.SCD4X(i2c)
print("Serial number:", [hex(i) for i in scd4x.serial_number])
scd4x.start_periodic_measurement()
print("Waiting for first measurement....")

text_value.text = "  40"
arc_measure(40, 0, 101, 101, 100)

# code reader setup
# The code reader has the I2C ID of hex 0c, or decimal 12.
TINY_CODE_READER_I2C_ADDRESS = 0x0C
TINY_CODE_READER_LENGTH_OFFSET = 0
TINY_CODE_READER_LENGTH_FORMAT = "H"
TINY_CODE_READER_MESSAGE_OFFSET = TINY_CODE_READER_LENGTH_OFFSET + struct.calcsize(TINY_CODE_READER_LENGTH_FORMAT)
TINY_CODE_READER_MESSAGE_SIZE = 254
TINY_CODE_READER_MESSAGE_FORMAT = "B" * TINY_CODE_READER_MESSAGE_SIZE
TINY_CODE_READER_I2C_FORMAT = TINY_CODE_READER_LENGTH_FORMAT + TINY_CODE_READER_MESSAGE_FORMAT
TINY_CODE_READER_I2C_BYTE_COUNT = struct.calcsize(TINY_CODE_READER_I2C_FORMAT)

# let sensors stabilize
print("Initializing sensors...")
time.sleep(2.3)
text_value.text = "  60"
arc_measure(60, 0, 101, 101, 100)
try:
    ssid = os.getenv('CIRCUITPY_WIFI_SSID')
    pw = os.getenv('CIRCUITPY_WIFI_PASSWORD')
except:
    print("Could not find WiFi info. Check your settings.toml file!")
    wifi_connect = False
    tile_grid.hidden = True
else:
    connect_wifi(False)

text_value.text = "  80"
arc_measure(80, 0, 101, 101, 100)

# set up MQTT
# Create a socket pool
pool = socketpool.SocketPool(wifi.radio)

# Set up a MiniMQTT Client
mqtt_client = MQTT.MQTT(
    broker=HOST,
    port=PORT,
    is_ssl=False,
    keep_alive=3600,
    socket_pool=pool
)

# Setup the callback methods above
mqtt_client.on_connect = connected
mqtt_client.on_disconnect = disconnected
mqtt_client.on_message = message
#mqtt_client.on_subscribe = subscribe

connect_mqtt(0)

text_value.text = " 100"
arc_measure(100, 0, 101, 101, 100)
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

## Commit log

2025-08-08 Update README.md
    Updated case information.
2025-09-10 Delete schematic-mini.pdf
    Replaced by newer jpg
2025-09-11 Add mqtt loop error check
    [code.py]
2025-09-11 Newer version
    Added diode.
2025-09-11 Updated schematic
    Added diode, renamed LED.
